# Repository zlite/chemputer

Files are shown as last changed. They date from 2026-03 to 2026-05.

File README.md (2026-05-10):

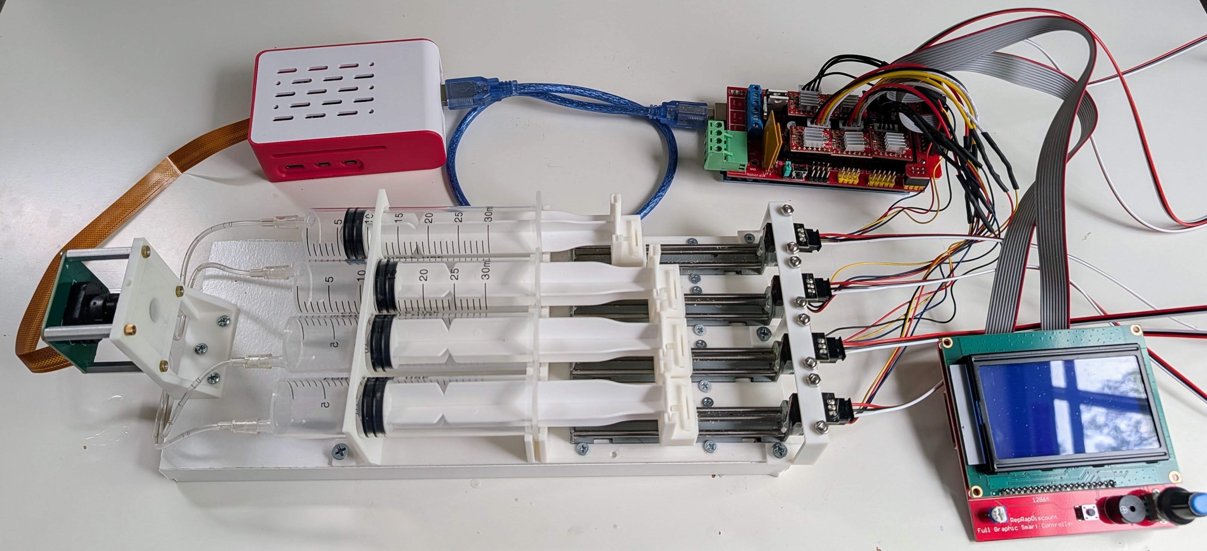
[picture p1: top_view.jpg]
Overview

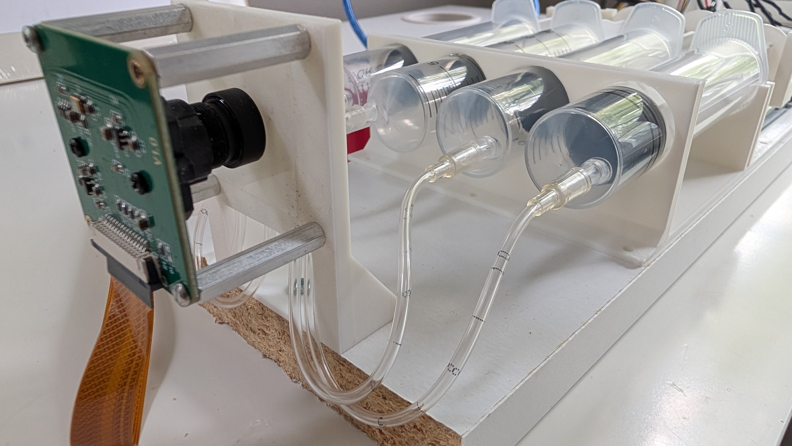
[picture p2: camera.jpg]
Camera


Files for a <$100 minimum "chemputer" that can do closed-loop self-driving lab (SDL) experiments such as color mixing as shown in [this demo](https://lab-automaton.replit.app). 

It has four syringe drives, a 3D-printed microfluidic (actually, more precisely "millifluidic") panel for mixing and a camera mount for color and other measurements. Requires a RaspberryPi

Inside the millifluidic mixer plate is shown here, with three tubes coming into the mixing chamber and one coming out below, with a vent tube at the top to avoid pressure issues

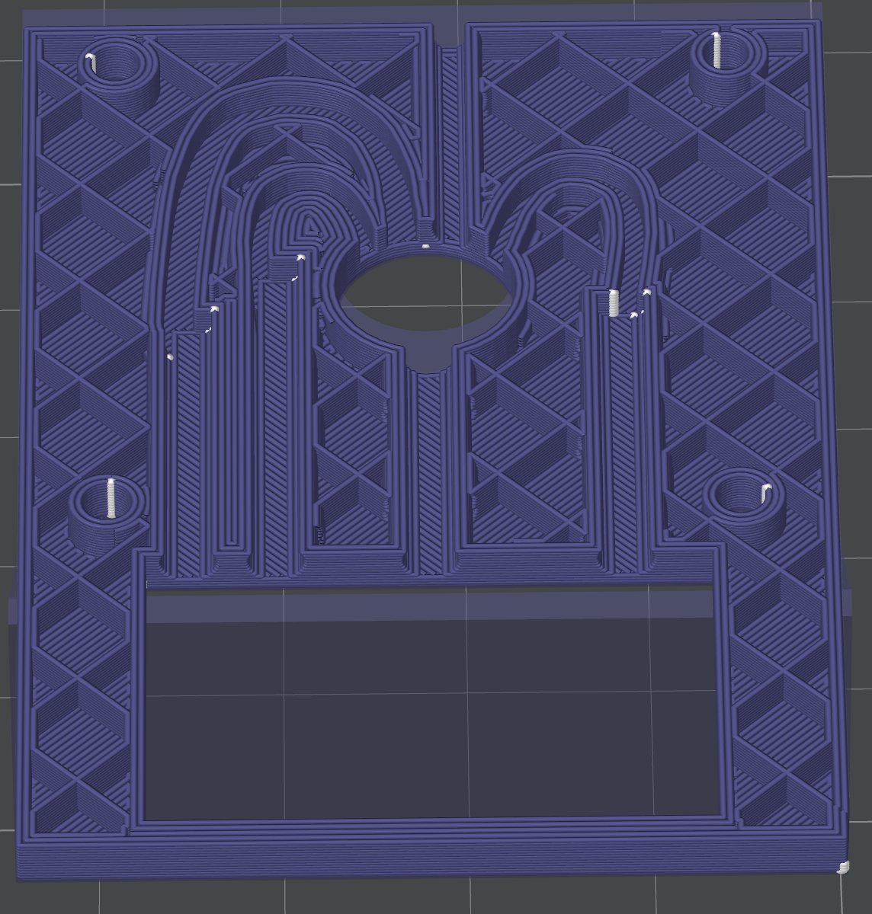
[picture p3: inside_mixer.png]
Mixer panel


BOM:
- [Steppers with lead screws for linear motion](https://amzn.to/4tf6lsl)
- [Cables with correct 4-pin connectors (splice them into stepper cables, replacing existing connector, which is too small)](https://amzn.to/4tilaLk)
- [Camera](https://amzn.to/4sIcuxi)
- A RaspberryPi of some sort. Pi4b or Pi5 recommended (4GB is fine).
- [RepRap Ramps 1.6 controller](https://amzn.to/4cumjs3)
- [Arduino Mega](https://amzn.to/4cNtHji)
- [Limit switches](https://amzn.to/4sIrRps)
- [30ml syringes](https://amzn.to/4sSEuhK)
- [Solonoid valve for purge line](https://amzn.to/4sHWMS9)
- [Standoffs](https://amzn.to/4mCUNNK)

## Instructions:

For the Ramps 1.6 board:

First, don’t get the older Ramps 1.4 version, which has serious design and QA problems in my experience; among other things the D9 out doesn’t work.

The software that the standard Chinese Ramps manufacturer steers you to is probably broken and rubbish (wrong settings for the LCD panel, which won’t work, and expecting all sorts of 3D printer stuff, like temperature sensors, that you don’t have). Ignore their instructions!

Instead, do this: 

Download the modified Marlin software [here](https://github.com/V1EngineeringInc/MarlinBuilder/releases) (it’s adapted for CNC machines, but that won’t be a problem)

Unzip the files, including the source code zip file inside that zip. In the Arduino IDE, open Marlin.ino from the source folder and that will open a bunch of other files. You’re going to need to go into the library manager and install some libraries as well: U8glib-HAL and U8lib.

Once you’ve installed them, you should be able to compile the code for the Arduino Mega and upload it. This will run and show a menu on the LCD, if you have one. 

To get steppers moving, use Gcode via the Arduino Serial terminal (250000 baud):

G91
G1 X10 F60
G1 X-10 F60

Will move X

M18 will turn off hold current on the steppers if they’re getting hot when not moving.

## Software

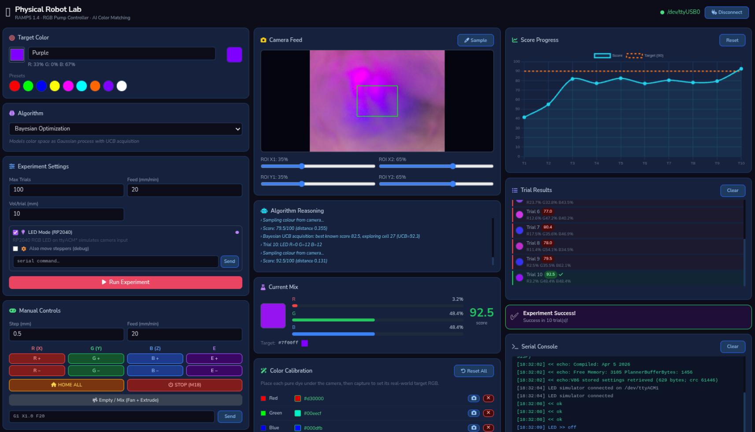
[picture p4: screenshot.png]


Git clone this repo into your RaspberryPi into a directory called pi_app. Run setup.sh. Run the app with this command ``` .venv/bin/python app.py```. Open the app in a browser on the Pi with localhost:5000 or remotely with [pi IP address]:5000

## Using a RGB LED to fake the colors

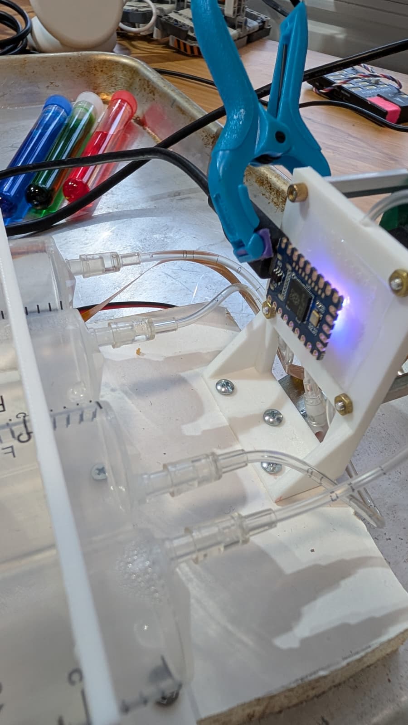
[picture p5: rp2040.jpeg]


If you want to use a RP2040 to fake the colored water to avoid water mess while you're testing, I recommend a [Waveshare RP2040-zero](https://amzn.to/4ck8JIR) which you can clamp onto the other side of the mixing chamber window as shown. Switch the RP2040 to CircuitPython by holding down the boot button when you plug it in via USB on your PC and copy over the CircuitPython image you download [here](https://circuitpython.org/board/waveshare_rp2040_zero/) to the drive that shows up. The drive will change its name from "RPI-RP2" to "CIRCUITPY" as explained [here](https://learn.adafruit.com/welcome-to-circuitpython/installing-circuitpython). Copy "neopixel.mpy" from this repo into the "lib" folder on this drive, then copy "code.py" into the root directory. It will start showing rainbow colors, which indicates that you did it right. Plug the board into one of your Pi's USB ports. Once you start the SDL app and click the LED Mode checkbox, the app wil talk to the RP2040 and will change its colors as needed for the experiments.

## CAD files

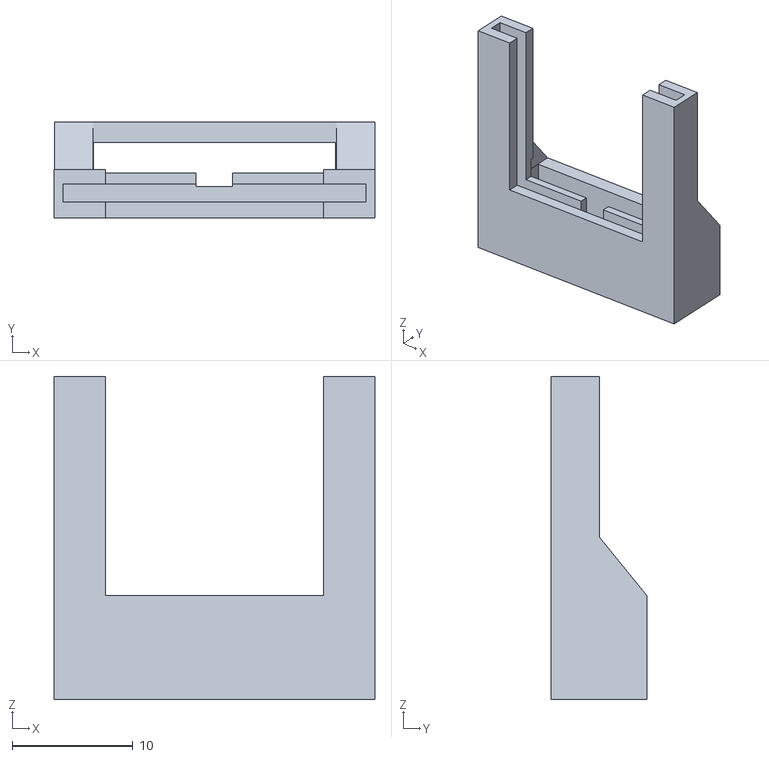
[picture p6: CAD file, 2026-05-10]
syringe holder.stl
26.5 x 7.90 x 26.7

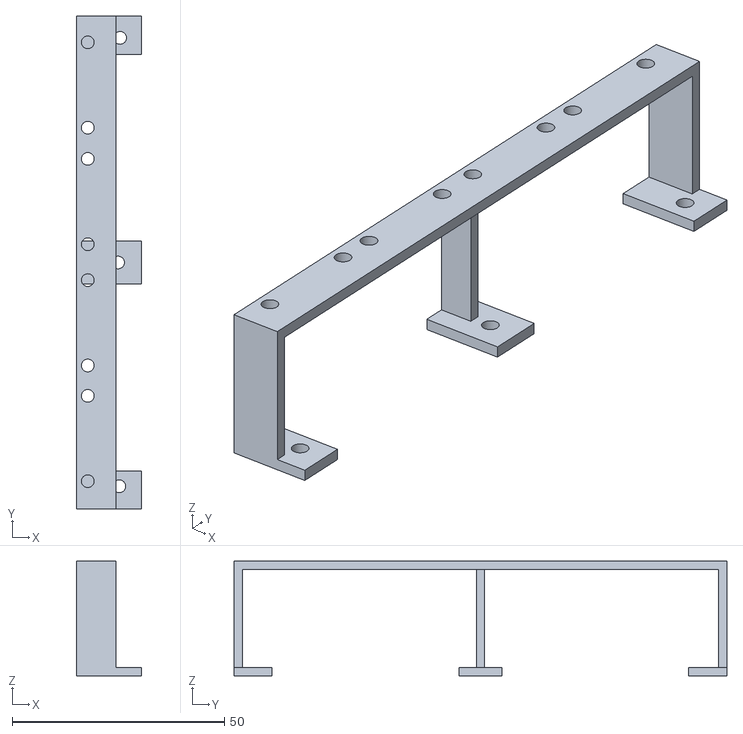
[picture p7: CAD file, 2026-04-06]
endstop_mount.stl
15.2 x 116.1 x 27.0

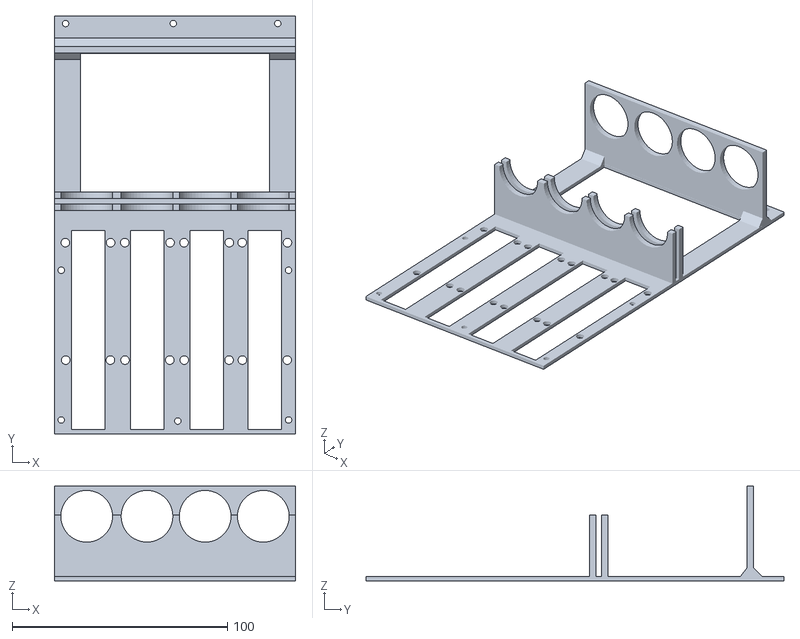
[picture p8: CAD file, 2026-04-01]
base.stl
112.0 x 194.0 x 44.0

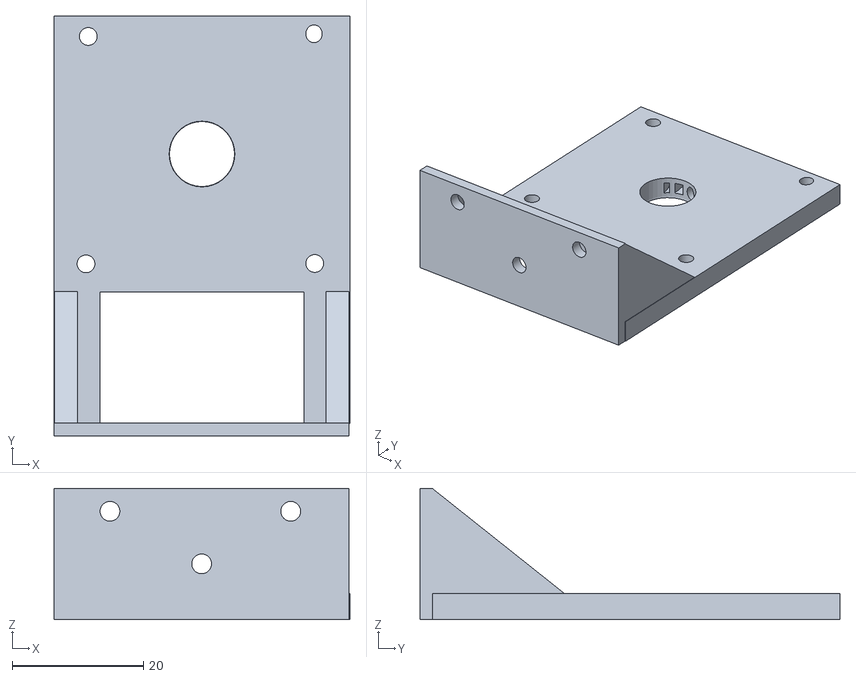
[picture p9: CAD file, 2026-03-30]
camera mount and mixer plate.stl
45.0 x 63.9 x 20.0

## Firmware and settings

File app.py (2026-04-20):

"""
Physical Robot Lab — Raspberry Pi Flask Server
Controls a RAMPS 1.4 board via serial for RGB liquid mixing experiments.

Axis mapping (same as original tkinter app):
  R  → X axis (Red pump)
  G  → Y axis (Green pump)
  B  → Z axis (Blue pump)
  E  → E axis (auxiliary / extrude)
  Empty → fan pulse + extrude

Run on Pi (first time):
  bash setup.sh
Then every time:
  .venv/bin/python app.py
Then open http://<pi-ip>:5000 in a browser.
"""

import glob
import json
import math
import os
import queue
import threading
import time
from collections import deque
from typing import Optional

import serial
from flask import Flask, Response, jsonify, render_template, request, stream_with_context

from learning import (
    ALGORITHMS,
    color_distance,
    calculate_score,
    normalized_rgb_to_hex,
    create_algorithm_state,
    get_algorithm_initial_guess,
    get_algorithm_next_guess,
)

# ─────────────────────────────────────────── constants ──

BAUD = 250_000
HOME_POSITION = -7    # mm — endstops stop axes here
HOME_FEED = 20        # mm/min for homing

AXIS_MAP = {"R": "X", "G": "Y", "B": "Z", "E": "E"}

# How many mm of pump travel equals one "full tube" of liquid
# Adjust this to calibrate your actual pump displacement
TOTAL_VOLUME_MM = 0.1

# Region of interest (fraction of frame) for color sampling
# [x_start, y_start, x_end, y_end] as fractions 0-1
DEFAULT_ROI = [0.35, 0.35, 0.65, 0.65]

# Camera device index (0 = default, or Pi camera via v4l2)
CAMERA_INDEX = 0

# RP2040 LED simulator
LED_BAUD = 115_200

# File where camera-calibrated color targets are persisted
CALIBRATION_FILE = os.path.join(os.path.dirname(__file__), "calibration.json")

# ─────────────────────────────────────────── Flask app ──

app = Flask(__name__)

# ─────────────────────────────── calibration storage ──

_cal_lock = threading.Lock()

def _load_calibration() -> dict:
    try:
        with open(CALIBRATION_FILE) as f:
            return json.load(f)
    except (FileNotFoundError, json.JSONDecodeError):
        return {}

def _save_calibration(data: dict):
    with open(CALIBRATION_FILE, "w") as f:
        json.dump(data, f, indent=2)

calibration: dict = _load_calibration()

# ─────────────────────────────────────── global state ──

class RobotState:
    def __init__(self):
        self.ser: Optional[serial.Serial] = None
        self.connected = False
        self.port_name = ""
        self._lock = threading.Lock()

        self.log_queue: deque = deque(maxlen=500)
        self._sse_queues: list[queue.Queue] = []
        self._sse_lock = threading.Lock()

        # Experiment state
        self.experiment_running = False
        self.experiment_thread: Optional[threading.Thread] = None

        # LED simulator (RP2040)
        self.led_ser: Optional[serial.Serial] = None
        self.led_connected = False
        self.led_lock = threading.Lock()

        # Camera state
        self.camera = None
        self.camera_lock = threading.Lock()
        self.roi = list(DEFAULT_ROI)

        self.step_mm = 0.5
        self.feed_mm_min = 20.0

    # ── serial helpers ──────────────────────────────────

    def connect(self) -> dict:
        with self._lock:
            try:
                if self.ser and self.ser.is_open:
                    self.connected = False
                    self.ser.close()

                port = _find_serial_port()
                if port is None:
                    raise serial.SerialException(
                        "No USB serial device found (/dev/ttyUSB* or /dev/ttyACM*)"
                    )

                self.ser = serial.Serial(port, BAUD, timeout=1)
                time.sleep(2)  # wait for board reset after DTR toggle

                self.connected = True
                self.port_name = port
                self._log(f"Connected to {port} at {BAUD} baud", "info")

                threading.Thread(target=self._reader, daemon=True).start()

                # Startup sequence
                self._send_raw("M302 S0")  # allow cold extrusion
                self._send_raw("M120")      # enable endstops
                self._send_raw("G91")       # relative positioning

                return {"ok": True, "port": port}

            except serial.SerialException as exc:
                self.connected = False
                self.port_name = ""
                self._log(f"Connection error: {exc}", "error")
                return {"ok": False, "error": str(exc)}

    def disconnect(self):
        with self._lock:
            self.connected = False
            if self.ser and self.ser.is_open:
                self.ser.close()
            self._log("Disconnected", "info")

    def send(self, cmd: str) -> bool:
        with self._lock:
            return self._send_raw(cmd)

    def _send_raw(self, cmd: str) -> bool:
        if not self.connected or not self.ser or not self.ser.is_open:
            self._log("Not connected — command dropped", "error")
            return False
        try:
            self.ser.write((cmd.strip() + "\n").encode())
            self._log(f">> {cmd}", "sent")
            return True
        except serial.SerialException as exc:
            self._log(f"Send error: {exc}", "error")
            return False

    def _reader(self):
        while self.connected and self.ser and self.ser.is_open:
            try:
                if self.ser.in_waiting:
                    line = self.ser.readline().decode(errors="replace").strip()
                    if line:
                        self._log(f"<< {line}", "recv")
            except Exception:
                break
            time.sleep(0.01)

    # ── camera helpers ──────────────────────────────────

    def open_camera(self):
        try:
            from picamera2 import Picamera2
            import cv2
            with self.camera_lock:
                if self.camera is None:
                    cam = Picamera2()
                    config = cam.create_preview_configuration(
                        main={"size": (640, 480), "format": "RGB888"}
                    )
                    cam.configure(config)
                    cam.start()
                    self.camera = cam
            return True
        except Exception:
            return False

    def get_frame_jpeg(self) -> Optional[bytes]:
        try:
            import cv2
            import numpy as np
            with self.camera_lock:
                if self.camera is None:
                    return None
                frame = self.camera.capture_array()
                # picamera2 "RGB888" format returns BGR array (OpenCV convention)
                # Draw ROI rectangle
                h, w = frame.shape[:2]
                x1 = int(self.roi[0] * w)
                y1 = int(self.roi[1] * h)
                x2 = int(self.roi[2] * w)
                y2 = int(self.roi[3] * h)
                cv2.rectangle(frame, (x1, y1), (x2, y2), (0, 255, 0), 2)
                _, buf = cv2.imencode(".jpg", frame, [cv2.IMWRITE_JPEG_QUALITY, 75])
                return buf.tobytes()
        except Exception:
            return None

    def sample_roi_color(self) -> Optional[tuple[float, float, float]]:
        """Return mean normalized RGB (0-1) from the ROI, or None."""
        try:
            import cv2
            import numpy as np
            with self.camera_lock:
                if self.camera is None:
                    return None
                frame = self.camera.capture_array()
                # picamera2 "RGB888" format returns BGR array (OpenCV convention)
                h, w = frame.shape[:2]
                x1 = int(self.roi[0] * w)
                y1 = int(self.roi[1] * h)
                x2 = int(self.roi[2] * w)
                y2 = int(self.roi[3] * h)
                roi_crop = frame[y1:y2, x1:x2]
                mean_bgr = cv2.mean(roi_crop)[:3]
                # BGR → RGB, normalize 0-1
                b, g, r = mean_bgr
                return (r / 255.0, g / 255.0, b / 255.0)
        except Exception:
            return None

    # ── LED simulator ───────────────────────────────────

    def open_led(self) -> dict:
        with self.led_lock:
            try:
                if self.led_ser and self.led_ser.is_open:
                    self.led_ser.close()
                port = _find_led_port(skip=self.port_name)
                if port is None:
                    return {"ok": False, "error": "No RP2040 found on ttyACM*"}
                self.led_ser = serial.Serial(port, LED_BAUD, timeout=1)
                time.sleep(1)  # wait for RP2040 reset after DTR
                self.led_connected = True
                self._log(f"LED simulator connected on {port}", "info")
                return {"ok": True, "port": port}
            except serial.SerialException as exc:
                self.led_connected = False
                self._log(f"LED connect error: {exc}", "error")
                return {"ok": False, "error": str(exc)}

    def close_led(self):
        with self.led_lock:
            self.led_connected = False
            if self.led_ser and self.led_ser.is_open:
                self.led_ser.close()
            self._log("LED simulator disconnected", "info")

    def set_led_rgb(self, r: int, g: int, b: int) -> bool:
        """Send R,G,B (0–25) to the RP2040 as 'R,G,B\r'."""
        with self.led_lock:
            if not self.led_ser or not self.led_ser.is_open:
                return False
            try:
                self.led_ser.write(f"{r},{g},{b}\r".encode())
                return True
            except serial.SerialException:
                return False

    # ── SSE broadcast ───────────────────────────────────

    def _log(self, msg: str, tag: str = "info"):
        entry = {"ts": time.strftime("%H:%M:%S"), "msg": msg, "tag": tag}
        self.log_queue.append(entry)
        self._broadcast("log", entry)

    def _broadcast(self, event: str, data: dict):
        with self._sse_lock:
            dead = []
            for q in self._sse_queues:
                try:
                    q.put_nowait({"event": event, "data": data})
                except queue.Full:
                    dead.append(q)
            for q in dead:
                self._sse_queues.remove(q)

    def subscribe(self) -> queue.Queue:
        q: queue.Queue = queue.Queue(maxsize=200)
        with self._sse_lock:
            self._sse_queues.append(q)
        return q

    def unsubscribe(self, q: queue.Queue):
        with self._sse_lock:
            if q in self._sse_queues:
                self._sse_queues.remove(q)

    def broadcast_experiment(self, event: str, data: dict):
        self._broadcast(event, data)


robot = RobotState()


# ─────────────────────────────────────── helpers ──

def _find_serial_port() -> Optional[str]:
    candidates = glob.glob("/dev/ttyUSB*") + glob.glob("/dev/ttyACM*")
    return candidates[0] if candidates else None


def _find_led_port(skip: str = "") -> Optional[str]:
    """Find RP2040 on a ttyACM port. Prefers by VID, falls back to any ACM not in use."""
    from serial.tools import list_ports
    RP2040_VID = 0x2E8A  # Raspberry Pi USB vendor ID
    acm_ports = sorted(p for p in glob.glob("/dev/ttyACM*") if p != skip)
    # Prefer a port whose USB VID matches the RP2040
    for info in list_ports.comports():
        if info.vid == RP2040_VID and info.device in acm_ports:
            return info.device
    # Fall back to first available ACM port not used by RAMPS
    return acm_ports[0] if acm_ports else None


def _pump_rgb(r_pct: float, g_pct: float, b_pct: float, feed: float = 20.0):
    """Dispense R/G/B proportions. Values are 0-100 percentages summing to 100."""
    r_mm = TOTAL_VOLUME_MM * r_pct / 100.0
    g_mm = TOTAL_VOLUME_MM * g_pct / 100.0
    b_mm = TOTAL_VOLUME_MM * b_pct / 100.0

    if r_mm > 0.001:
        robot.send(f"G1 X{r_mm:.3f} F{feed:.0f}")
        time.sleep(0.1)
    if g_mm > 0.001:
        robot.send(f"G1 Y{g_mm:.3f} F{feed:.0f}")
        time.sleep(0.1)
    if b_mm > 0.001:
        robot.send(f"G1 Z{b_mm:.3f} F{feed:.0f}")
        time.sleep(0.1)
    robot.send("M18")  # disable steppers


def _fan_pulse_and_mix():
    """Fan on for 2s (mixing) then off. Also extrudes 0.5mm to stir."""
    robot.send("M106 S255")
    robot.send("G1 E0.5 F20")
    time.sleep(2.2)
    robot.send("M106 S0")
    robot.send("M18")


def _home_all():
    robot.send(f"G1 X{HOME_POSITION} Y{HOME_POSITION} Z{HOME_POSITION} F{HOME_FEED}")
    time.sleep(1.0)
    robot.send("G92 X0 Y0 Z0 E0")
    robot.send("M18")


# ─────────────────────────────────── experiment runner ──

def _run_experiment(target_name: str, target_rgb: dict, algorithm_name: str,
                    max_trials: int, feed: float, use_camera: bool,
                    led_mode: bool = False, also_move_steppers: bool = False):
    """Background thread: runs one full color-matching experiment."""
    try:
        robot.experiment_running = True
        target = (target_rgb["r"], target_rgb["g"], target_rgb["b"])

        robot.broadcast_experiment("experiment_start", {
            "target_name": target_name,
            "target_rgb": target_rgb,
            "algorithm": algorithm_name,
            "max_trials": max_trials,
            "led_mode": led_mode,
        })

        if led_mode:
            robot.broadcast_experiment("reasoning", {"msg": "LED mode — no homing needed"})
        else:
            robot.broadcast_experiment("reasoning", {"msg": "Homing all axes..."})
            _home_all()
            time.sleep(0.5)

        history = []
        algo_state = create_algorithm_state(algorithm_name)
        guess = get_algorithm_initial_guess(algorithm_name, algo_state, target, target_name, [])

        for trial in range(1, max_trials + 1):
            if not robot.experiment_running:
                break

            if led_mode:
                # Each channel independent (0-1 → 0-25); no normalisation
                r_val = int(max(0.0, min(1.0, guess[0])) * 25)
                g_val = int(max(0.0, min(1.0, guess[1])) * 25)
                b_val = int(max(0.0, min(1.0, guess[2])) * 25)
                r_pct = round(guess[0] * 100, 1)
                g_pct = round(guess[1] * 100, 1)
                b_pct = round(guess[2] * 100, 1)

                robot.broadcast_experiment("trial_start", {
                    "trial": trial,
                    "r": r_pct, "g": g_pct, "b": b_pct,
                })
                robot.broadcast_experiment("reasoning", {
                    "msg": f"Trial {trial}: LED R={r_val} G={g_val} B={b_val}"
                })

                robot.set_led_rgb(r_val, g_val, b_val)

                if also_move_steppers and robot.connected:
                    total = guess[0] + guess[1] + guess[2]
                    if total > 0:
                        sp = [v / total * 100 for v in guess[:3]]
                    else:
                        sp = [33.3, 33.3, 33.4]
                    robot.broadcast_experiment("reasoning", {
                        "msg": f"Debug: moving steppers R={sp[0]:.1f}% G={sp[1]:.1f}% B={sp[2]:.1f}%"
                    })
                    _pump_rgb(sp[0], sp[1], sp[2], feed)

                time.sleep(0.3)  # let camera settle on new colour

                # Score — camera required in LED mode
                robot.broadcast_experiment("reasoning", {"msg": "Sampling colour from camera..."})
                sampled = robot.sample_roi_color()
                if sampled:
                    sr, sg, sb = sampled
                    dist = color_distance(sampled, target)
                    score = calculate_score(dist)
                    mix_hex = normalized_rgb_to_hex(sr, sg, sb)
                else:
                    sr, sg, sb = guess[0], guess[1], guess[2]
                    dist = color_distance((sr, sg, sb), target)
                    score = calculate_score(dist)
                    mix_hex = normalized_rgb_to_hex(sr, sg, sb)
                    robot.broadcast_experiment("reasoning", {
                        "msg": "Camera unavailable — using LED values as estimate"
                    })

                step_result = {
                    "trial": trial,
                    "r": r_pct, "g": g_pct, "b": b_pct,
                    "score": round(score, 1),
                    "mix_hex": mix_hex,
                }
                history.append({"rgb": (guess[0], guess[1], guess[2]), "score": score})

            else:
                r_pct = round(guess[0] * 100, 1)
                g_pct = round(guess[1] * 100, 1)
                b_pct = round(guess[2] * 100, 1)

                # Normalise so percents sum to 100
                total = r_pct + g_pct + b_pct
                if total > 0:
                    r_pct = r_pct / total * 100
                    g_pct = g_pct / total * 100
                    b_pct = b_pct / total * 100
                else:
                    r_pct, g_pct, b_pct = 33.3, 33.3, 33.4

                robot.broadcast_experiment("trial_start", {
                    "trial": trial,
                    "r": round(r_pct, 1), "g": round(g_pct, 1), "b": round(b_pct, 1),
                })
                robot.broadcast_experiment("reasoning", {
                    "msg": f"Trial {trial}: pumping R={r_pct:.1f}% G={g_pct:.1f}% B={b_pct:.1f}%"
                })

                _pump_rgb(r_pct, g_pct, b_pct, feed)

                robot.broadcast_experiment("reasoning", {"msg": "Mixing (fan pulse)..."})
                _fan_pulse_and_mix()
                time.sleep(0.5)

                if use_camera:
                    robot.broadcast_experiment("reasoning", {"msg": "Sampling color from camera..."})
                    sampled = robot.sample_roi_color()
                    if sampled:
                        sr, sg, sb = sampled
                        dist = color_distance(sampled, target)
                        score = calculate_score(dist)
                        mix_hex = normalized_rgb_to_hex(sr, sg, sb)
                    else:
                        sr, sg, sb = r_pct / 100.0, g_pct / 100.0, b_pct / 100.0
                        dist = color_distance((sr, sg, sb), target)
                        score = calculate_score(dist)
                        mix_hex = normalized_rgb_to_hex(sr, sg, sb)
                        robot.broadcast_experiment("reasoning", {
                            "msg": "Camera unavailable — using simulated score"
                        })
                else:
                    sr, sg, sb = r_pct / 100.0, g_pct / 100.0, b_pct / 100.0
                    dist = color_distance((sr, sg, sb), target)
                    score = calculate_score(dist)
                    mix_hex = normalized_rgb_to_hex(sr, sg, sb)

                step_result = {
                    "trial": trial,
                    "r": round(r_pct, 1), "g": round(g_pct, 1), "b": round(b_pct, 1),
                    "score": round(score, 1),
                    "mix_hex": mix_hex,
                }
                history.append({
                    "rgb": (r_pct / 100, g_pct / 100, b_pct / 100),
                    "score": score,
                })

            robot.broadcast_experiment("trial_result", step_result)
            robot.broadcast_experiment("reasoning", {
                "msg": f"Score: {score:.1f}/100 (distance {dist:.3f})"
            })

            if score >= 90:
                robot.broadcast_experiment("experiment_end", {
                    "success": True,
                    "trials": trial,
                    "score": round(score, 1),
                    "mix_hex": mix_hex,
                    "msg": f"Success in {trial} trial(s)!",
                })
                return

            if trial < max_trials:
                algo_history = [{"rgb": h["rgb"], "score": h["score"]} for h in history]
                guess = get_algorithm_next_guess(
                    algorithm_name, algo_state, algo_history, target,
                    lambda msg: robot.broadcast_experiment("reasoning", {"msg": msg})
                )

        robot.broadcast_experiment("experiment_end", {
            "success": False,
            "trials": max_trials,
            "score": round(history[-1]["score"], 1) if history else 0,
            "mix_hex": history[-1].get("mix_hex", "#888888") if history else "#888888",
            "msg": f"Reached max trials ({max_trials}) without success.",
        })

    except Exception as exc:
        robot.broadcast_experiment("experiment_end", {
            "success": False,
            "trials": 0,
            "score": 0,
            "mix_hex": "#888888",
            "msg": f"Experiment error: {exc}",
        })
    finally:
        robot.experiment_running = False


# ─────────────────────────────────────────── routes ──

@app.route("/")
def index():
    return render_template("index.html", algorithms=list(ALGORITHMS.keys()))


# ── serial ──────────────────────────────────────────────

@app.route("/api/connect", methods=["POST"])
def api_connect():
    result = robot.connect()
    return jsonify(result)


@app.route("/api/disconnect", methods=["POST"])
def api_disconnect():
    robot.disconnect()
    return jsonify({"ok": True})


@app.route("/api/status")
def api_status():
    return jsonify({
        "connected": robot.connected,
        "port": robot.port_name,
        "experiment_running": robot.experiment_running,
        "led_connected": robot.led_connected,
    })


# ── manual controls ──────────────────────────────────────
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

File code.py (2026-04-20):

import sys
import time

import board
import neopixel
import supervisor


NUM_PIXELS = 1
NEOPIXEL_PIN = board.GP16
BRIGHTNESS = 0.2
STEP_DELAY = 0.02
STEP_SIZE = 5


pixels = neopixel.NeoPixel(
    NEOPIXEL_PIN,
    NUM_PIXELS,
    brightness=BRIGHTNESS,
    auto_write=True,
)


def wheel(pos: int) -> tuple[int, int, int]:
    pos %= 256
    if pos < 85:
        return 255 - pos * 3, pos * 3, 0
    if pos < 170:
        pos -= 85
        return 0, 255 - pos * 3, pos * 3
    pos -= 170
    return pos * 3, 0, 255 - pos * 3


def clamp_byte(value: int) -> int:
    return max(0, min(255, value))


def parse_color(command: str):
    command = command.strip()
    if not command:
        return None

    lowered = command.lower()
    if lowered in ("help", "?"):
        return "help"
    if lowered in ("rainbow", "auto"):
        return "rainbow"
    if lowered in ("off", "black"):
        return (0, 0, 0)

    if command.startswith("#") and len(command) == 7:
        try:
            return (
                int(command[1:3], 16),
                int(command[3:5], 16),
                int(command[5:7], 16),
            )
        except ValueError:
            return None

    parts = [part.strip() for part in command.split(",")]
    if len(parts) == 3:
        try:
            return tuple(clamp_byte(int(part)) for part in parts)
        except ValueError:
            return None

    return None


def show_help():
    print("Send one of these commands, then press Enter:")
    print("  255,0,128   -> set RGB directly")
    print("  #FF0080     -> set RGB as hex")
    print("  rainbow     -> resume rainbow cycle")
    print("  off         -> turn LED off")


print("RP2040-Zero RGB serial control ready.")
show_help()

line_buffer = ""
mode = "rainbow"
current_color = (0, 0, 0)
rainbow_pos = 0


while True:
    while supervisor.runtime.serial_bytes_available:
        char = sys.stdin.read(1)
        if char in ("\r", "\n"):
            command = line_buffer.strip()
            line_buffer = ""
            if not command:
                continue

            result = parse_color(command)
            if result == "help":
                show_help()
            elif result == "rainbow":
                mode = "rainbow"
                print("Mode: rainbow")
            elif isinstance(result, tuple):
                mode = "solid"
                current_color = result
                pixels[0] = current_color
                print("Color set to {},{},{}".format(*current_color))
            else:
                print("Could not parse command:", command)
                show_help()
        else:
            line_buffer += char

    if mode == "rainbow":
        pixels[0] = wheel(rainbow_pos)
        rainbow_pos = (rainbow_pos + STEP_SIZE) % 256

    time.sleep(STEP_DELAY)

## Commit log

2026-03-30 Create camera mount and mixer plate.stl
    [camera mount and mixer plate.stl]
2026-03-30 Add README with project details and BOM
    Added project overview and bill of materials.
2026-03-30 Format BOM links as markdown list
2026-03-30 Add 30ml syringes to BOM list in README
2026-04-01 Updated files
    [base.stl, endstops.stl]
2026-04-01 Update BOM items in README.md
2026-04-15 Update RaspberryPi recommendation in BOM
2026-04-15 Add standoffs to the list of components
2026-04-20 Add Ramps 1.6 board instructions to README
    Added instructions for using the Ramps 1.6 board, including software setup and Gcode commands for controlling steppers.
2026-04-20 Enhance README with RGB LED RP2040 setup instructions
    Added instructions for using a RGB LED with RP2040 for testing.
2026-05-10 Improved syringe holder to be more robust
    [syringe holder.stl]
